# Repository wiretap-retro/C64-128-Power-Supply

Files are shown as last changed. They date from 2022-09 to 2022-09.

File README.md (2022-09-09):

# C64/C128 Power Supply
This power supply is a simple design for the C64 or C128.

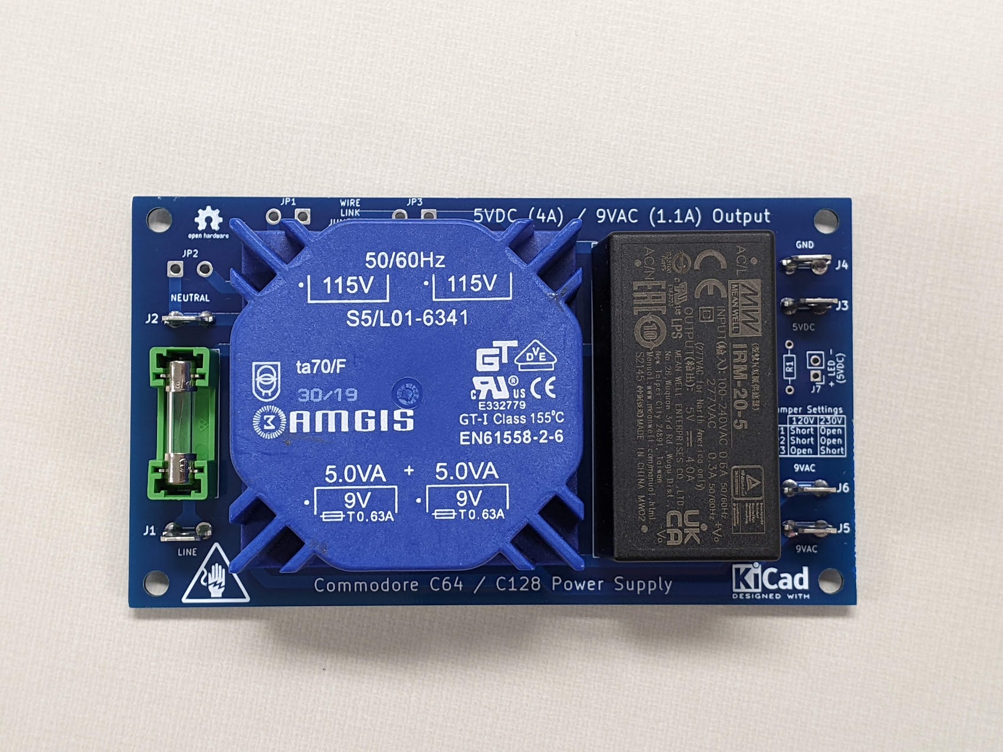
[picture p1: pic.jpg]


## Assembly
* Order the PCB from your choice of PCB fab. (JLCPCB, PCBway, OSH Park, etc.)
* Order the parts necessary as listed in the BOM. (The transformer can be substituted with a Talema 70041k if you can't find the Amgis)
* Solder the fuse holder, spade connectors, resistor, and pin header. Alternatively, an LED can be fit directly in place of the pin header.
* Solder the Meanwell 5V power supply and the transformer.
* Observe the jumper settings on the board near the 5V power LED. For 120V outlets, JP1 and JP2 require a wire link jumper. For 230V outlets, JP3 requires a wire link jumper.
* Grab a spare NEMA 1-15 or 5-15 cable and cut the female end off, stripping the wire insulation. Spare the ground cable if using a NEMA 5-15, as it isn't used. As for countries outside of North America, use an appropriate quality cable that matches your outlet.
* Install female spade connector fittings on your power plug wires that match the size of the male fittings on the PCB. They're found at any auto store.
* For the Commodore side of the connector, you can make your own cable with a 7-pin DIN, or cut the end off an old failed power supply. Follow the Commodore spec for your connections, using a multimeter for confirmation, as the wire colors may not always be correct.
* I don't have a case for this yet, but you can put it in a project box, mounted using the 4 holes provided on the PCB. If you're really inclined, make a 3D printed enclosure and please share files with the community. 
* Connect the power cables, insert the fuse, and start using it.

## Project Status
This power supply has been tested and confirmed working by numerous people. No issues have been reported.

## Other
This is an open source project. Feel free to do what you want with it.

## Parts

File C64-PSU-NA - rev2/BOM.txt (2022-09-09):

Digikey P/N
‎TE2245-ND‎ --- Amgis L01-6341 (1 of these)
1866-3042-ND‎ --- Meanwell IRM-20-5 (1 of these)
F6790-ND‎ --- Littlefuse 0PTF0075P (1 of these)
507-1261-ND‎ --- Bel Fuse 5MF 1-R (1 of these)

Mouser P/N
571-1-726386-2 --- TE Connectivity 1-726386-2 (6 of these)

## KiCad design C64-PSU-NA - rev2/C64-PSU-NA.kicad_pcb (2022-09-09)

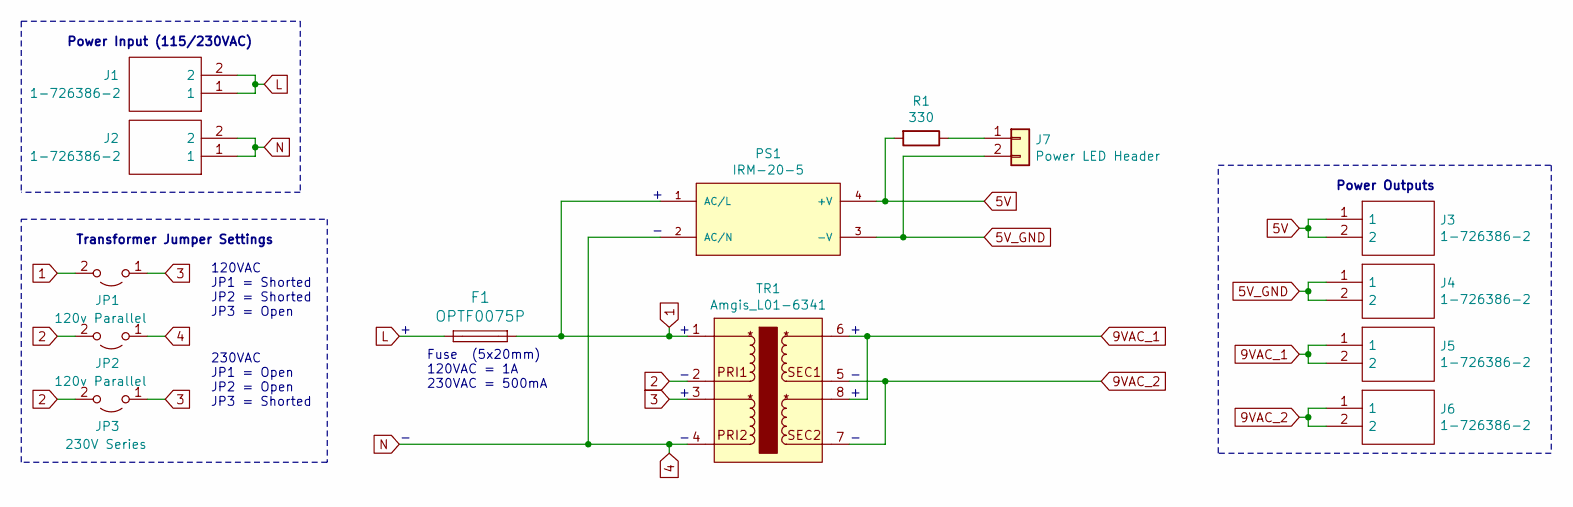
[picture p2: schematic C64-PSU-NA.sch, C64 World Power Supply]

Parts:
F1: OPTF0075P; 0PTF0075P
J1, J2, J3, J4, J5, J6: 1-726386-2; 17263862; Mouser Part Number 571-1-726386-2
J7: Power LED Header; PinHeader_1x02_P2.54mm_Vertical
JP1, JP2: 120v Parallel; SolderWire-0.75sqmm_1x02_P4.8mm_D1.25mm_OD2.3mm
JP3: 230V Series; SolderWire-0.75sqmm_1x02_P4.8mm_D1.25mm_OD2.3mm
PS1: IRM-20-5; CONV_IRM-20-5
R1: 330; R_Axial_DIN0204_L3.6mm_D1.6mm_P7.62mm_Horizontal
TR1: Amgis_L01-6341

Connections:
1: F1.2, JP1.2 (B), PS1.1 (AC/L), TR1.1
2: JP2.2 (B), JP3.2 (B), TR1.2
3: JP1.1 (A), JP3.1 (A), TR1.3
4: J2.1, J2.2, JP2.1 (A), PS1.2 (AC/N), TR1.4
5V: J3.1, J3.2, PS1.4 (+V), R1.2
5V_GND: J4.1, J4.2, J7.2, PS1.3 (-V)
9VAC_1: J5.1, J5.2, TR1.6, TR1.8
9VAC_2: J6.1, J6.2, TR1.5, TR1.7
L: F1.1, J1.1, J1.2
unnamed: J7.1, R1.1

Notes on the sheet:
Power Outputs
Power Input (115/230VAC)
Transformer Jumper Settings
120VAC JP1 = Shorted JP2 = Shorted JP3 = Open
230VAC JP1 = Open JP2 = Open JP3 = Shorted
Fuse (5x20mm) 120VAC = 1A 230VAC = 500mA

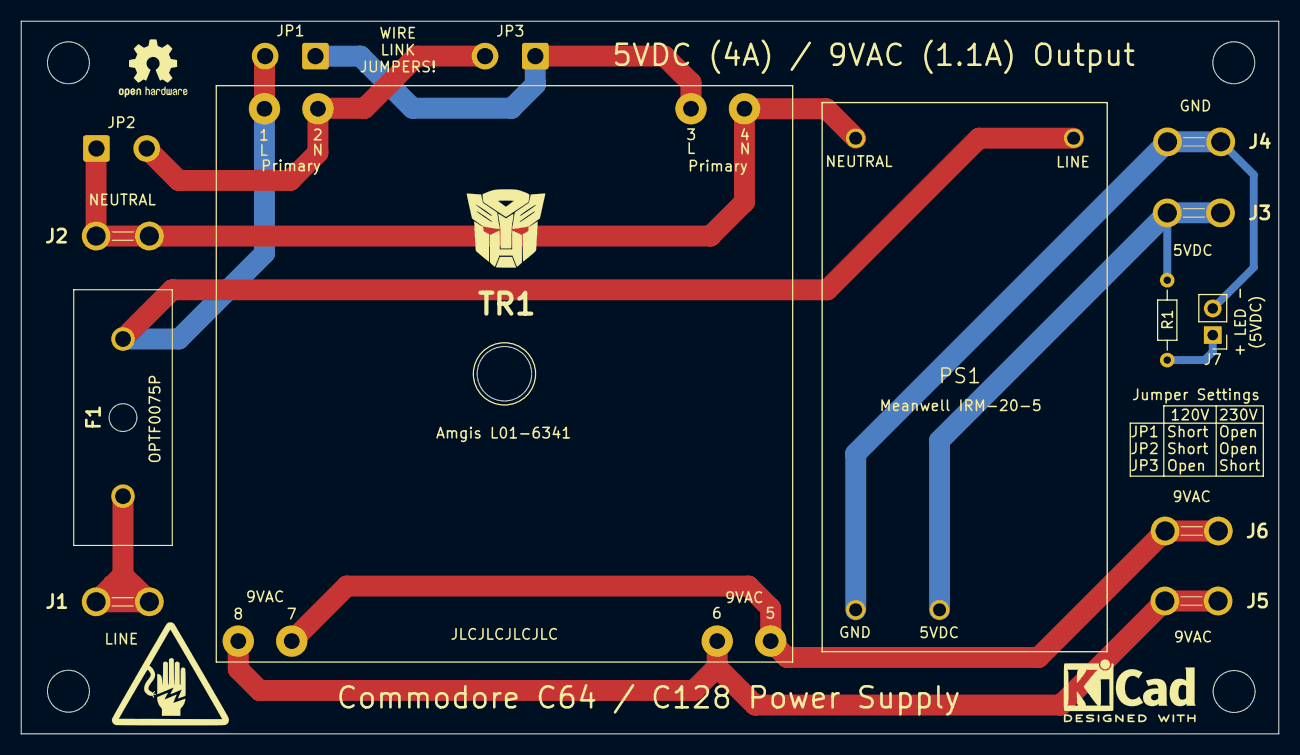
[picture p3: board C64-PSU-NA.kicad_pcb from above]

Board: 2 copper layers, 120.0 x 68.0 mm, 14 parts (0 on the bottom side), 10 nets.
